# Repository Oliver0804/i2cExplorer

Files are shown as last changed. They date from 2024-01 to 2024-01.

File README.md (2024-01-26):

# i2cExplorer
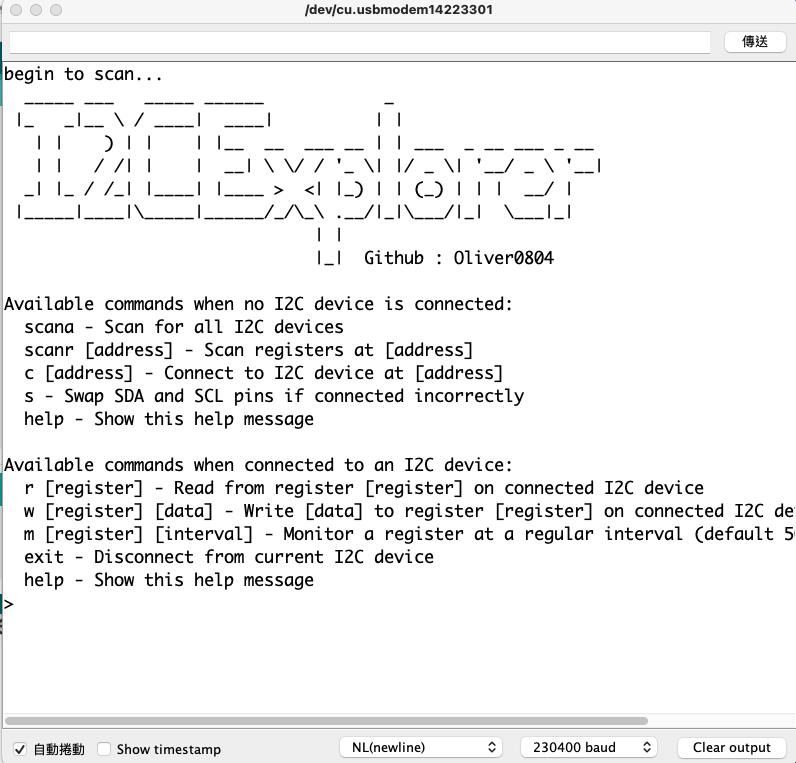
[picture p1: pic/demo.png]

## Introduction

https://www.youtube.com/watch?v=PAolOif3dD0&ab_channel=BashCat
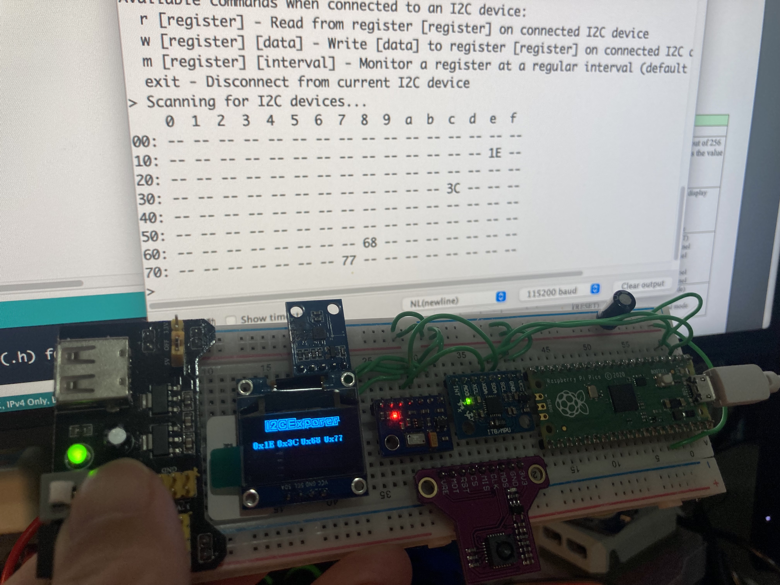
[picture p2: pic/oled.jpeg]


i2cExplorer is a powerful tool designed for exploring I2C devices on the bus using the RP2040 as the MCU within the Arduino framework. It allows users to interact with I2C devices via a serial interface, providing capabilities for scanning, reading, and writing I2C registers.

『I2C Explorer』是一個非常實用的工具，特別適合於解決在使用I2C通訊協議時可能遇到的一些常見問題和場景。以下是幾個典型的使用場景，以及I2C Explorer如何幫助解決這些問題：
1. 不知道I2C裝置的地址：在開發I2C應用時，常常需要知道連接到I2C總線的裝置地址。如果文檔不清楚或者你正在使用未標記的硬件，I2C Explorer的掃描功能（scana命令）可以掃描總線上的所有裝置，幫助你快速找到每個裝置的地址。
2. 混淆了SDA和SCL線：有時可能會不小心將SDA（數據線）和SCL（時鐘線）接反。I2C Explorer提供了一個方便的命令（s命令），可以在不重新布線的情況下軟件層面上交換這兩條線，從而糾正連接錯誤。
3. 探索特定I2C裝置的寄存器：當你需要了解某個特定I2C裝置的內部寄存器結構時，I2C Explorer的寄存器掃描功能（scanr命令）可以讀取並顯示連接到指定地址的I2C裝置的所有寄存器信息。
4. 讀取或寫入I2C裝置的寄存器：在開發和調試階段，直接從串口讀取或寫入I2C裝置的寄存器是非常有用的。I2C Explorer通過提供讀取（r命令）和寫入（w命令）命令，使這一過程變得簡單快捷。

I2C Explorer is an extremely practical tool, particularly suited for addressing common problems and scenarios encountered when using the I2C communication protocol. Below are several typical use cases, and how the I2C Explorer helps in resolving these issues:
1. Unknown I2C Device Address: During the development of I2C applications, it's often necessary to know the addresses of devices connected to the I2C bus. If documentation is unclear or you are working with unmarked hardware, the scanning feature (scana command) of I2C Explorer can scan all devices on the bus, helping you quickly find the address of each device.
2. Confusion between SDA and SCL Lines: Sometimes, you might accidentally reverse the SDA (data line) and SCL (clock line). I2C Explorer offers a convenient command (s command) that swaps these two lines at the software level without the need for rewiring, thereby correcting the connection error.
3. Exploring the Registers of a Specific I2C Device: When you need to understand the internal register structure of a particular I2C device, the register scanning feature (scanr command) of I2C Explorer can read and display all the register information of the device connected to a specified address.
4. Reading or Writing to I2C Device Registers: During the development and debugging phases, directly reading from or writing to the registers of an I2C device through the serial port is very useful. I2C Explorer simplifies this process by providing commands for reading (r command) and writing (w command).

## Hardware Setup
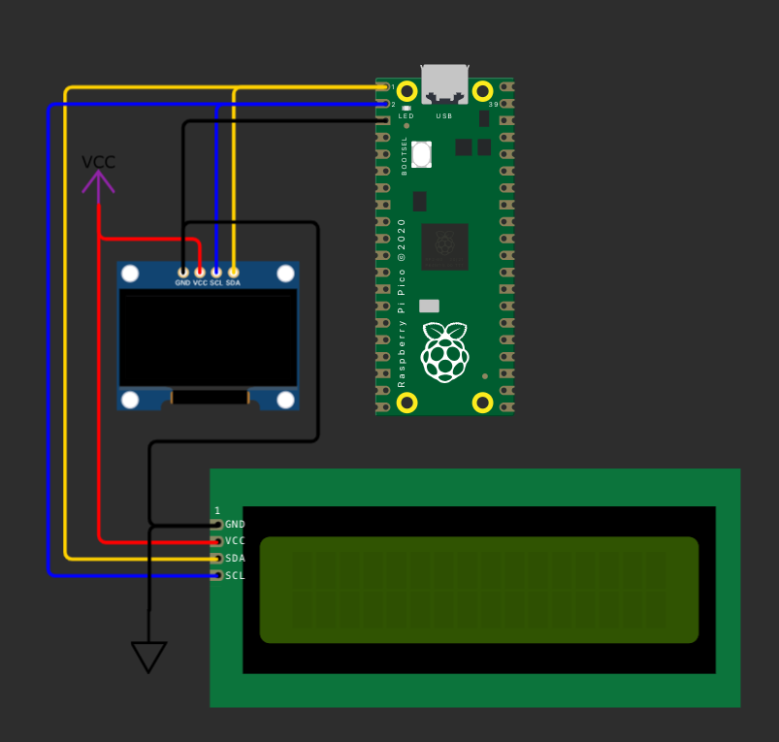
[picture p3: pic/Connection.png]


Connect any I2C device to your RP2040, using the following pins:
- SDA (Serial Data Line): Connect to GP0 on the Pico.
- SCL (Serial Clock Line): Connect to GP1 on the Pico.
Ensure that your I2C devices are compatible with the RP2040's voltage levels and properly powered.

## Features
- I2C Bus Scanning: Detect all I2C devices connected to the RP2040.
- Read I2C Registers: Read values from specified registers of the connected I2C devices.
- Write I2C Registers: Write data to specified registers of the connected I2C devices.
- Monitor I2C Registers: Continuously read and print values from a specific register at regular intervals.
- Serial Interface: Communicate with the RP2040 and I2C devices through a serial connection.
- Swap I2C bus ( SDA <-> SCL )
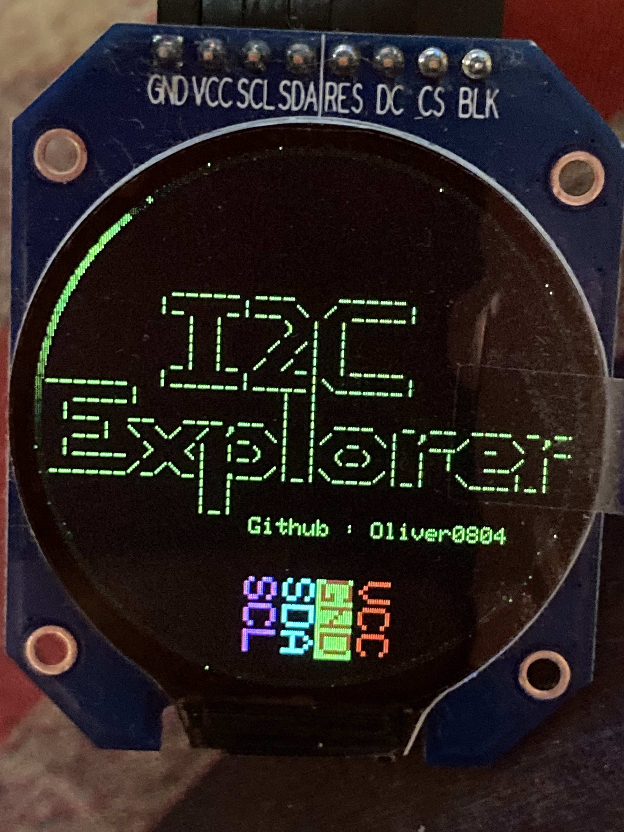
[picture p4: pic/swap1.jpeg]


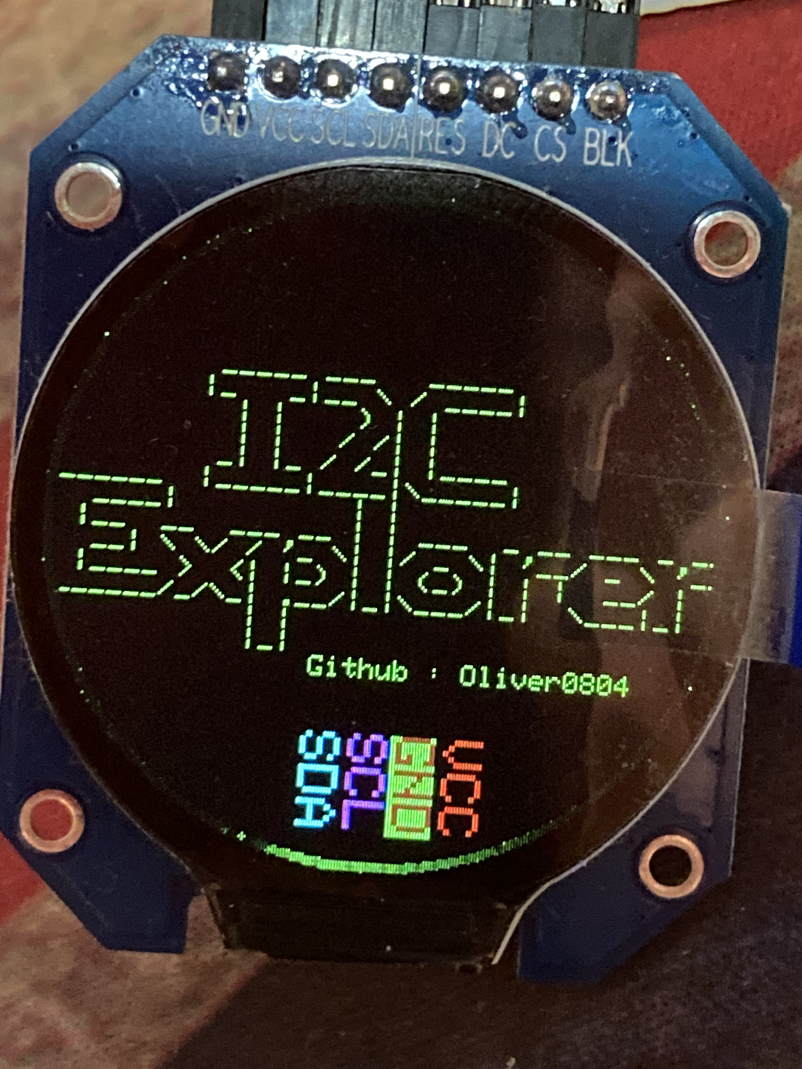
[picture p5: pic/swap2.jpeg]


## Usage
### Command List
Execute the following commands through your serial terminal:

```
- `scana`: Scan all I2C devices on the bus.
- `scanr [address]`: Scan registers at the specified I2C address.
- `c [address]`: Connect to an I2C device at the given address.
- `r [register]`: Read from a register on the connected I2C device.
- `w [register] [data]`: Write data to a register on the connected I2C device.
- `m [register] [interval]`: Monitor a register at the specified interval (in milliseconds).
- `s` - Swap SDA and SCL pins if connected incorrectly
- `exit`: Disconnect from the current I2C device.
- `help`: Display available commands based on the connection status.
```
#### scana
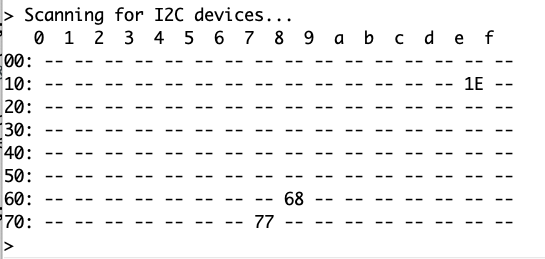
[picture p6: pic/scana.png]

#### c 0x68 and r 0x75


## Monitoring Interval
For the m command, the interval is optional (default is 500ms). The maximum allowed interval is 3000ms.

## Example

```
> scana
> c 0x68
> r 0x1
> w 0x1 0xFF
> m 0x1 1000
> exit
```
## PCB HW(Kicad 7)
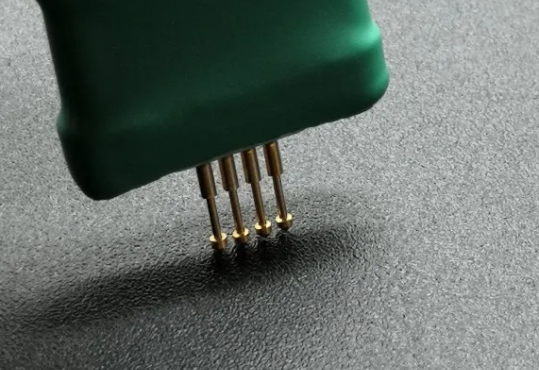
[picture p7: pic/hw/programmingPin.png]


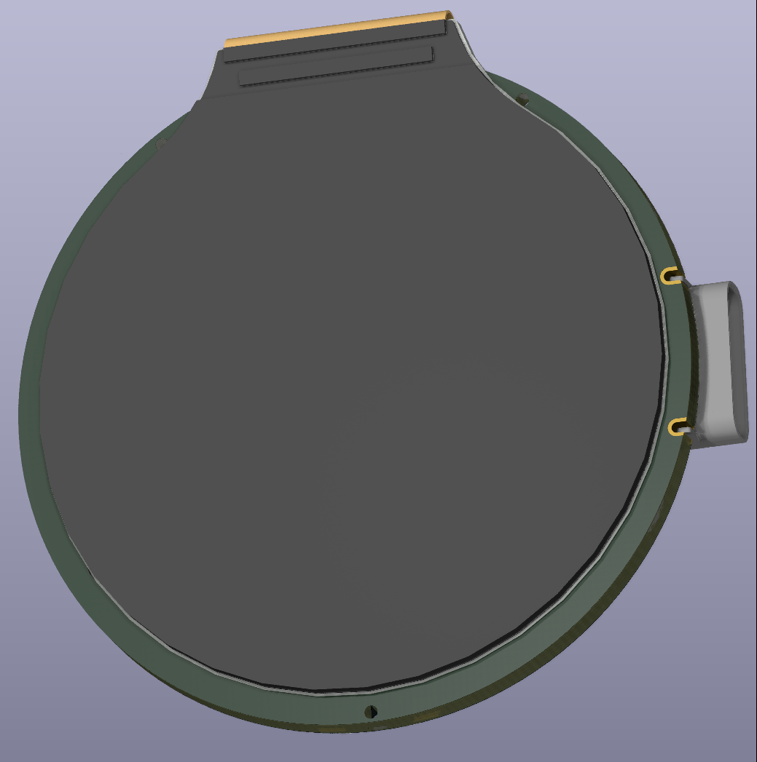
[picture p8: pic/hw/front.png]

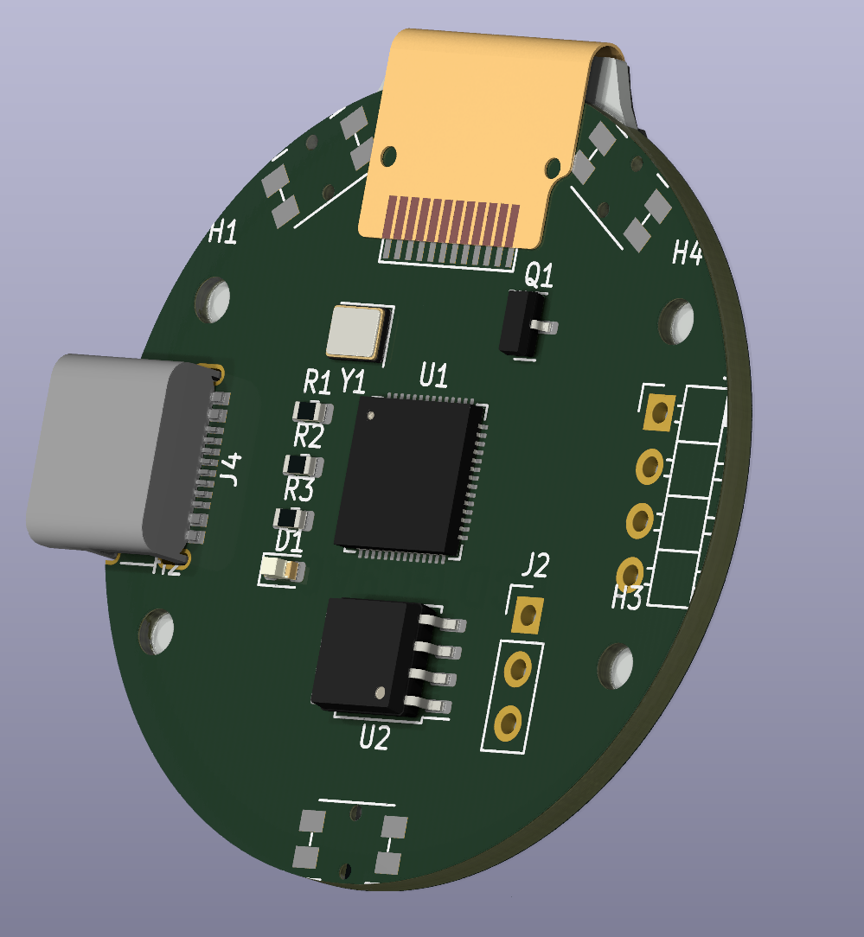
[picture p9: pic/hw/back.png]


## Note
Ensure your RP2040 and I2C devices are correctly connected and configured.
This tool is intended for exploration and debugging purposes.

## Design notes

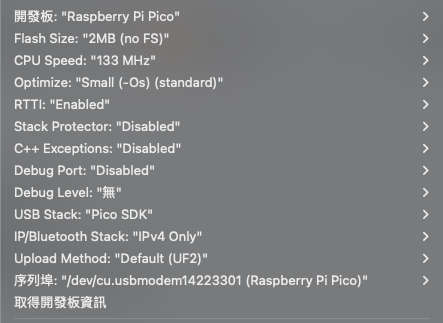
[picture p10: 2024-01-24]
pic/arduino_pico_config.png

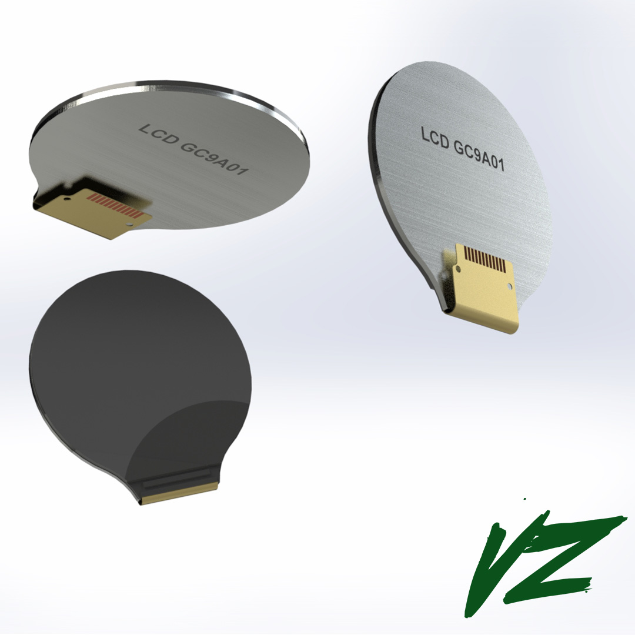
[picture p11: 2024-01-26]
HW/i2cExplorer/libaray/1-28-lcd-ga9a01-1.snapshot.1/GA9101.jpg

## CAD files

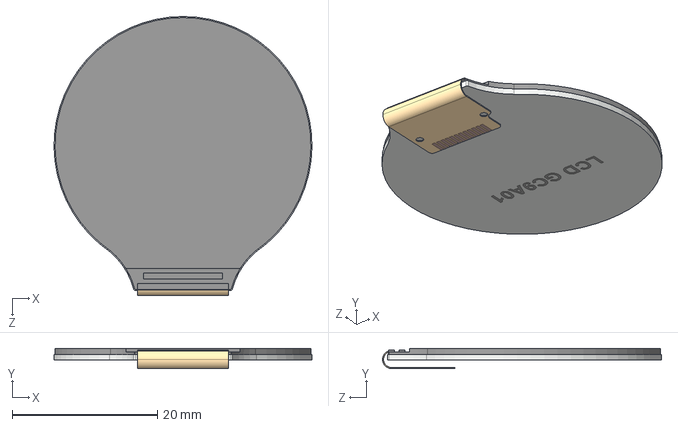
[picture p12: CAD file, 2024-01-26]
HW/i2cExplorer/libaray/1-28-lcd-ga9a01-1.snapshot.1/GC9A01.STEP
35.5 x 2.77 x 38.4 mm

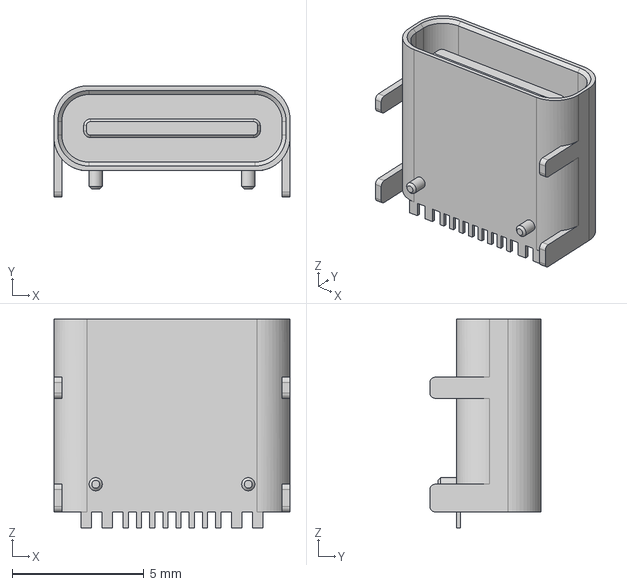
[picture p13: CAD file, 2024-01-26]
HW/i2cExplorer/libaray/HRO TYPE-C-31-M-12.step
8.94 x 4.21 x 7.90 mm

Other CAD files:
HW/i2cExplorer/libaray/1-28-lcd-ga9a01-1.snapshot.1/GC9A01.SLDPRT

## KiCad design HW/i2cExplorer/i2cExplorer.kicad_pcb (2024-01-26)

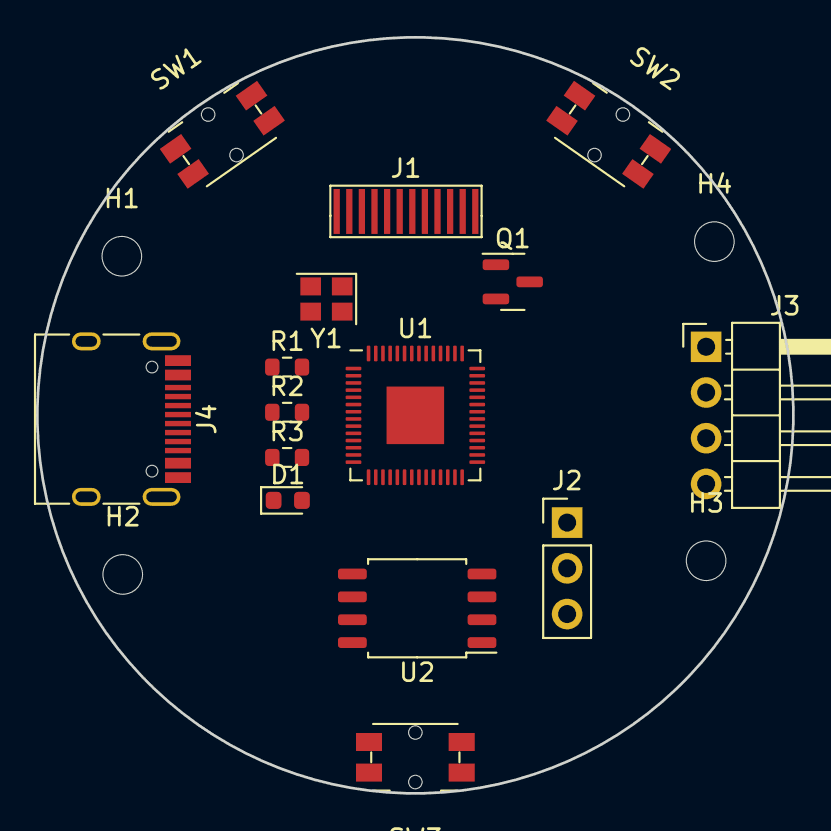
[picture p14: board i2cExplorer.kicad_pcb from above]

Board: 2 copper layers, 42.0 x 42.0 mm, 19 parts (0 on the bottom side), 4 nets, no tracks yet.

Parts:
D1: LED; LED_0603_1608Metric
H1, H2, H3, H4: MountingHole; MountingHole_2.2mm_M2
J1: GC9A01; GC9A01_Extended_FPC
J2: SWDIO; PinHeader_1x03_P2.54mm_Vertical
J3: I2CTest; PinHeader_1x04_P2.54mm_Horizontal
J4: USB_C_Receptacle; USB_C_Receptacle_HRO_TYPE-C-31-M-12
Q1: S8050; SOT-23
R1, R2, R3: R; R_0603_1608Metric
SW1, SW2, SW3: SW_Push; Panasonic_EVQPUM_EVQPUD
U1: RP2040; QFN-56-1EP_7x7mm_P0.4mm_EP3.2x3.2mm
U2: W5Q16JVSSIQ; SOIC-8_5.23x5.23mm_P1.27mm
Y1: Crystal; Crystal_SMD_2520-4Pin_2.5x2.0mm

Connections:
unnamed: J4.A1 (GND), J4.A12 (GND), J4.B1 (GND), J4.B12 (GND)
unnamed: J4.A4 (VBUS), J4.A9 (VBUS), J4.B4 (VBUS), J4.B9 (VBUS)
unnamed: U1.23 (DVDD), U1.50 (DVDD)
unnamed: U1.1 (IOVDD), U1.10 (IOVDD), U1.22 (IOVDD), U1.33 (IOVDD), U1.42 (IOVDD), U1.49 (IOVDD)

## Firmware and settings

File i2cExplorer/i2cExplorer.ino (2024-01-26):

/*
   https://github.com/earlephilhower/arduino-pico/releases/download/global/package_rp2040_index.json
   https://patorjk.com/software/taag/#p=display&h=3&f=Big&t=%20%20%20%20%20%20%20%20I2C%0AExporer
*/
#include <Wire.h>

#include <Arduino_GFX_Library.h>
#define GFX_BL DF_GFX_BL // default backlight pin, you may replace DF_GFX_BL to actual backlight pin

Arduino_DataBus *bus = new Arduino_SWSPI(8 /* DC */, 9 /* CS */, 10 /* SCK */, 11 /* MOSI */, -1 /* MISO */);
Arduino_GFX *gfx = new Arduino_GC9A01(bus, 12 /* RST */, 2 /* rotation */, true /* IPS */);

int connectedI2CAddress = -1;
#define PICO_ONBORAD_LED 25
#define PICO_ONBORAD_SDA 3
#define PICO_ONBORAD_SCL 2
#define PICO_ONBORAD_BTN 22
#define MAX_I2C_DEVICES 128

byte foundAddresses[MAX_I2C_DEVICES];
int foundCount = 0;

float angle = 0.0; // 旋转角度
float radius = 118.0; // 旋转半径
int centerX = gfx->width() / 2; // 圆心X坐标
int centerY = gfx->height() / 2; // 圆心Y坐标
float speed = 0.02; // 旋转速度
float rotationSpeed = 0.003; // 旋转速度，每毫秒旋转的弧度数


const int ledPin = 16; // 使用GP16引脚
unsigned long startTime = millis(); // 记录开始时间
const int interval = 1500; // 完整呼吸周期（毫秒）
const int lowerLimit = 20;  // 亮度下限
const int upperLimit = 250; // 亮度上限

#include "SoftwareI2C.h"
SoftwareI2C softwarei2c;
// 定义SDA和SCL引脚号
int sdaPin = PICO_ONBORAD_SDA;
int sclPin = PICO_ONBORAD_SCL;


void setup() {
  Serial.begin(230400);
  //while (!Serial) continue;
  gfxInit();
  gfxShowLogo();
  //Wire1.setSDA(PICO_ONBORAD_SDA);
  //Wire1.setSCL(PICO_ONBORAD_SCL);
  //Wire1.begin();
  softwarei2c.begin(sdaPin, sclPin);       // sda, scl

  pinMode(PICO_ONBORAD_LED, OUTPUT);
  pinMode(PICO_ONBORAD_BTN, INPUT_PULLUP);
  digitalWrite(PICO_ONBORAD_LED, HIGH);
  pinMode(ledPin, OUTPUT);
  digitalWrite(ledPin, HIGH);

  Serial.println("  _____ ___   _____ ______            _");
  Serial.println(" |_   _|__ \\ / ____|  ____|          | |");
  Serial.println("   | |    ) | |    | |__  __  ___ __ | | ___  _ __ ___ _ __");
  Serial.println("   | |   / /| |    |  __| \\ \\/ / '_ \\| |/ _ \\| '__/ _ \\ '__|");
  Serial.println("  _| |_ / /_| |____| |____ >  <| |_) | | (_) | | |  __/ |");
  Serial.println(" |_____|____|\\_____|______/_/\\_\\ .__/|_|\\___/|_|  \\___|_|");
  Serial.println("                               | |                 V1.0 ");
  Serial.println("                               |_|  Github : Oliver0804 ");
  showHelp(connectedI2CAddress != -1);
  showHelp(connectedI2CAddress != 1);
  digitalWrite(PICO_ONBORAD_LED, LOW);

  Serial.print("> ");

}


void loop() {
  readBTN();
  breathLED();
  rotatePoint();
  cmdParse();
}

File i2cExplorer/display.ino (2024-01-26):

void breathLED() {
  unsigned long currentTime = millis();
  float elapsed = (currentTime - startTime) % interval; // 计算经过时间的一部分
  float phase = (elapsed / interval) * TWO_PI; // 将时间映射到0到2π之间

  // 使用正弦波调整亮度
  float brightness = (sin(phase) + 1) / 2; // 将正弦波结果从-1~1映射到0~1
  brightness = lowerLimit + brightness * (upperLimit - lowerLimit); // 映射到亮度范围

  analogWrite(ledPin, int(brightness));
}

#define BLACK   0x0000
#define BROWN   0xA145 // 近似棕色
#define RED     0xF800
#define ORANGE  0xFD20 // 近似橙色
#define YELLOW  0xFFE0
#define GREEN   0x07E0
#define BLUE    0x001F
#define PURPLE  0x780F // 近似紫色
#define GRAY    0x8410 // 近似灰色
#define WHITE   0xFFFF
#define CYAN     0x07FF
#define MAGENTA  0xF81F

void gfxInit() {
  //Serial.println("Arduino_GFX");
#ifdef GFX_EXTRA_PRE_INIT
  GFX_EXTRA_PRE_INIT();
#endif
  if (!gfx->begin())
  {
    Serial.println("gfx->begin() failed!");
  }
  gfx->fillScreen(BLACK);

#ifdef GFX_BL
  pinMode(GFX_BL, OUTPUT);
  digitalWrite(GFX_BL, HIGH);
#endif


}
void gfxShowLogo() {
  gfx->setRotation(0);
  gfx->fillScreen(0x0000);  // 清屏
  gfx->setTextColor(0x07E0); // 设置文本颜色
  gfx->setTextSize(1); // 根据需要调整文本大小
  gfx->setTextWrap(false);  // 关闭文字自动换行

const char *lines[] = {
    "           _____ ___   _____              ",
    "          |_   _|__ \\ / ____|             ",
    "            | |    ) | |                  ",
    "            | |   / /| |                  ",
    "           _| |_ / /_| |____              ",
    "  ______  |_____|____|\\_____|             ",
    " |  ____|          | |                    ",
    " | |__  __  ___ __ | | ___  _ __ ___ _ __ ",
    " |  __| \\ \\/ / '_ \\| |/ _ \\| '__/ _ \\ '__|",
    " | |____ >  <| |_) | | (_) | | |  __/ |   ",
    " |______/_/\\_| .__/|_|\\___/|_|  \\___|_|   ",
    "             | |                          ",
    "             |_|                          ",
    "                 Github : Oliver0804      "
};


  int linesCount = sizeof(lines) / sizeof(lines[0]);
  int lineSpacing = 8; // 行间距
  int totalHeight = linesCount * lineSpacing; // 文本块总高度
  int startY = ((gfx->height() - totalHeight) / 2)-5; // 垂直居中

  for (int i = 0; i < linesCount; i++) {
    int lineLength = strlen(lines[i]) * 6; // 估算每行长度（每个字符宽度假设为6像素）
    int startX = (gfx->width() - lineLength) / 2; // 水平居中
    gfx->setCursor(startX, startY + i * lineSpacing);
    gfx->println(lines[i]);
  }
}
void rotatePoint() {
  static int oldX = 0;
  static int oldY = 0;
  static int oldFadeX = 0;
  static int oldFadeY = 0;
  unsigned long currentTime = millis();
  
  float elapsed = currentTime - startTime;

  // 根据经过的时间计算旋转角度
  float angle = elapsed * rotationSpeed;
  angle = fmod(angle, TWO_PI); // 保持角度在0到2π之间

  // 计算点的新位置
  int x = centerX + radius * cos(angle);
  int y = centerY + radius * sin(angle);

  // 清除旧点和绘制新点的逻辑保持不变...
  gfx->fillCircle(oldX, oldY, 2, 0x0000); // 使用背景颜色覆盖旧点
  for (float t = 0; t < 1; t += 0.1) {
    oldFadeX = centerX + radius * cos(angle - t);
    oldFadeY = centerY + radius * sin(angle - t);
    gfx->fillCircle(oldFadeX, oldFadeY, 1, 0x0000); // 清除拖尾
  }

  // 绘制新的旋转点
  gfx->fillCircle(x, y, 1, 0x07E0); // 绘制绿色点，点半径为2

  // 绘制拖尾效果
  for (float t = 0; t < 1; t += 0.1) {
    int fadeX = centerX + radius * cos(angle - t);
    int fadeY = centerY + radius * sin(angle - t);
    uint16_t fadeColor = gfx->color565(0, 255 * (1 - t), 0); // 颜色逐渐减淡
    gfx->fillCircle(fadeX, fadeY, 1, fadeColor);
  }


  // 更新旧点位置
  oldX = x;
  oldY = y;
}
void rotatePoint_old() {
  static int oldX = 0;
  static int oldY = 0;
  static int oldFadeX = 0;
  static int oldFadeY = 0;

  // 更新角度
  angle += speed;
  if (angle > 2 * PI) {
    angle -= 2 * PI;
  }

  // 计算点的新位置
  int x = centerX + radius * cos(angle);
  int y = centerY + radius * sin(angle);

  // 清除旧点
  gfx->fillCircle(oldX, oldY, 2, 0x0000); // 使用背景颜色覆盖旧点
  for (float t = 0; t < 1; t += 0.1) {
    oldFadeX = centerX + radius * cos(angle - t);
    oldFadeY = centerY + radius * sin(angle - t);
    gfx->fillCircle(oldFadeX, oldFadeY, 1, 0x0000); // 清除拖尾
  }

  // 绘制新的旋转点
  gfx->fillCircle(x, y, 1, 0x07E0); // 绘制绿色点，点半径为2

  // 绘制拖尾效果
  for (float t = 0; t < 1; t += 0.1) {
    int fadeX = centerX + radius * cos(angle - t);
    int fadeY = centerY + radius * sin(angle - t);
    uint16_t fadeColor = gfx->color565(0, 255 * (1 - t), 0); // 颜色逐渐减淡
    gfx->fillCircle(fadeX, fadeY, 1, fadeColor);
  }

  // 更新旧点位置
  oldX = x;
  oldY = y;
}

void gfxTest() {
  gfx->setCursor(random(gfx->width()), random(gfx->height()));
  gfx->setTextColor(random(0xffff), random(0xffff));
  gfx->setTextSize(random(6) /* x scale */, random(6) /* y scale */, random(2) /* pixel_margin */);
  gfx->println("Hello World!");
}
void gfxShowi2c() {
  gfx->fillScreen(0x0000); // 清空屏幕
  if (foundCount == 0) {
    // 如果没有找到I2C设备
    gfx->setTextColor(0x0000, 0xF800); // 黑色字体，红色背景
    gfx->setTextSize(4);
    gfx->setCursor(10, (gfx->height() - 28) / 2); // 居中显示
    gfx->println("Not Found I2C");
  } else {
    // 如果找到了I2C设备
    for (int i = 0; i < foundCount; i++) {
      gfx->setCursor(random(gfx->width()), random(gfx->height()));
      gfx->setTextColor(0x07E0, 0x0000); // 绿色字体
      gfx->setTextSize(random(1, 6), random(1, 6), random(2)); // 随机字体大小和间距
      char buf[6];
      sprintf(buf, "0x%02X", foundAddresses[i]);
      gfx->println(buf);
    }
  }
}


void gfxDisplayI2cPin(int sdaPin, int sclPin) {
  gfxShowLogo() ;
  //gfx->fillScreen(0x0000); // 清空屏幕

  // 设置文本旋转为90度
  gfx->setRotation(1);
  int textX = 190;
  int textY = 85;
  int textYplus = 17;
  int y = 0;

  // 显示VCC和GND
  gfx->setTextSize(2); // 设置文字大小
  gfx->setTextColor(RED, BLACK);
  gfx->setCursor(textX, textY + (textYplus * y++)); // 设置文字位置
  gfx->println("VCC");

  gfx->setTextColor(BROWN, GREEN);
  gfx->setCursor(textX, textY + (textYplus * y++));
  gfx->println("GND");

  // 显示SDA和SCL，颜色根据引脚号变化
  uint16_t sdaColor = (sdaPin == 2 ? CYAN : MAGENTA);
  uint16_t sclColor = (sclPin == 3 ? MAGENTA : CYAN);
  uint16_t sdaBgColor = (sdaPin == 2 ? BLACK : BLACK);
  uint16_t sclBgColor = (sclPin == 3 ? BLACK : BLACK);
  gfx->setTextColor(sdaColor, sdaBgColor);
  gfx->setCursor(textX, textY + (textYplus * y++));
  gfx->println(sdaPin == 2 ? "SDA" : "SCL");

  gfx->setTextColor(sclColor, sclBgColor);
  gfx->setCursor(textX, textY + (textYplus * y++));
  gfx->println(sclPin == 3 ? "SCL" : "SDA");

  // 重置文本旋转为正常
  gfx->setRotation(0);
}

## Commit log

2024-01-24 add onboard led
2024-01-24 add pico json
2024-01-24 add pico config pic
2024-01-24 更新第一階段
2024-01-25 add led pwm
2024-01-25 整理代碼
2024-01-26 use soft i2c
2024-01-26 更新i2cScan使用軟體i2c
2024-01-26 添加i2c顯示狀態
2024-01-26 add kicad
    [GC9A01.SLDPRT, GC9A01.STEP, HRO TYPE-C-31-M-12.step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]
2024-01-26 update sch
    [i2cExplorer.kicad_pcb, i2cExplorer.kicad_sch]
